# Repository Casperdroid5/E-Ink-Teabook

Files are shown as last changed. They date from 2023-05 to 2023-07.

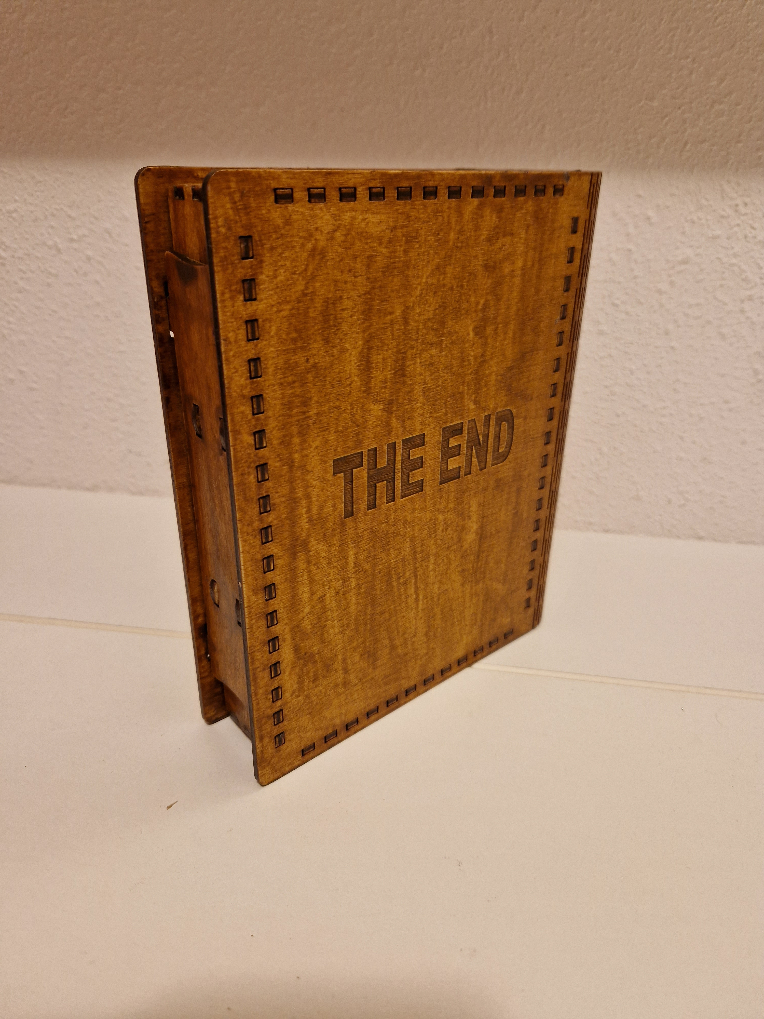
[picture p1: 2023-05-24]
Pictures/back.jpg

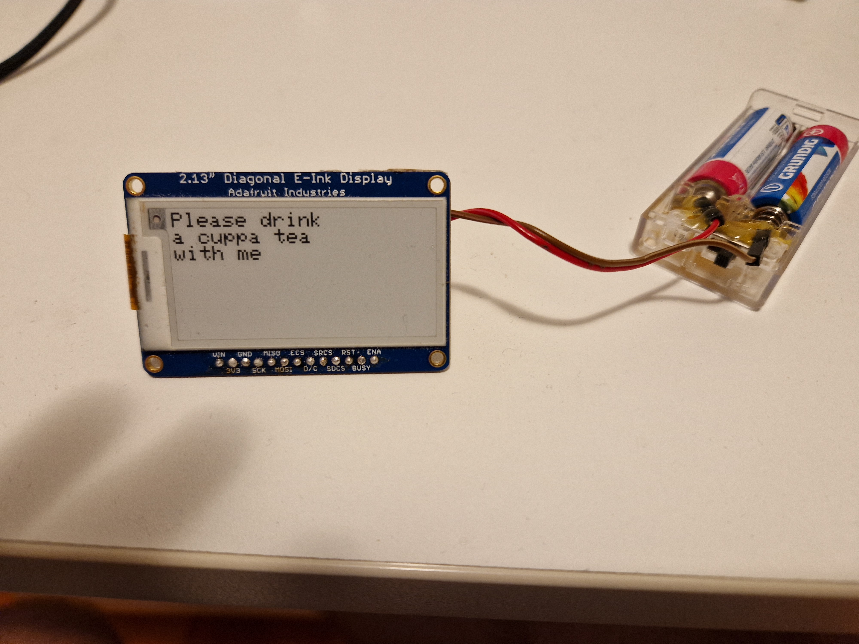
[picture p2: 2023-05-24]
Pictures/seperated display.jpg

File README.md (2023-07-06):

# E-Ink-Teabook

A Teabook with a built-in E-ink display that displays self-help, compliments, and funny texts every other day.

## Hardware Design

The E-Ink-Teabook is designed to be compatible with the following hardware components:

- Arduino Pro Mini 3.3V 8MHz: It is recommended to remove the power LED for energy preservation. Optionally, the voltage regulator can be removed, although it is less secure than leaving it intact.

- Power Source: The system can be powered by 2 AA batteries. However, for optimal performance and system stability, it is highly recommended to use a 4.5V power source such as 3 AA or 3 AAA batteries. Using lower voltage power sources may result in system instability, with the system failing at around 2.7V. The device is very low power with around 31uA current usage when "sleeping". This is thanks to the hardware design of Adafruit's E-ink display (ENA-pin for the ldo is very smart) and some software optimization in the code (low power librarys).

- Display: The Teabook features the Adafruit ThinkInk Mono 2.13-inch monochrome display in black and white. While this display provides excellent performance, there are more cost-effective alternatives available. I strongly advice using the Adafruit E-ink Friend board for a budget-friendly solution. Flexible displays are also an option, but note that the font size may be significantly larger compared to non-flexible displays when using Adafruit's libraries.

By combining the joy of tea with inspirational and humorous messages, the E-Ink-Teabook offers a unique and refreshing experience for daily use.

### Other designs

It is of course possible to use this project for other designs as well. You can think of multiple options:
- Daily motivation "Post-it"
- Daily fun facts painting
- Name tag

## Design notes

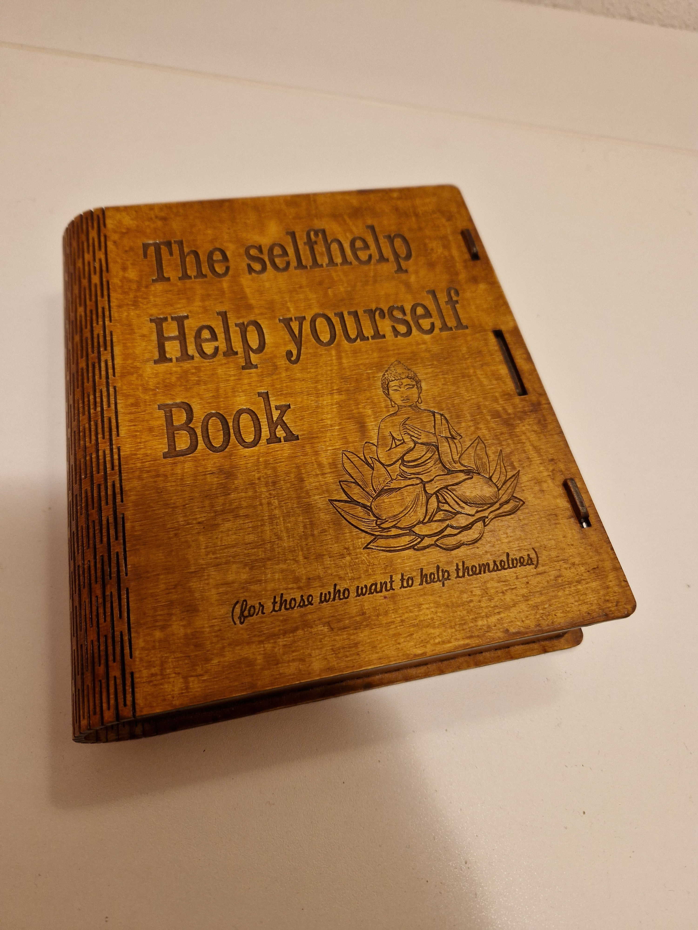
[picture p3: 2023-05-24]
Pictures/bookclosed.jpg

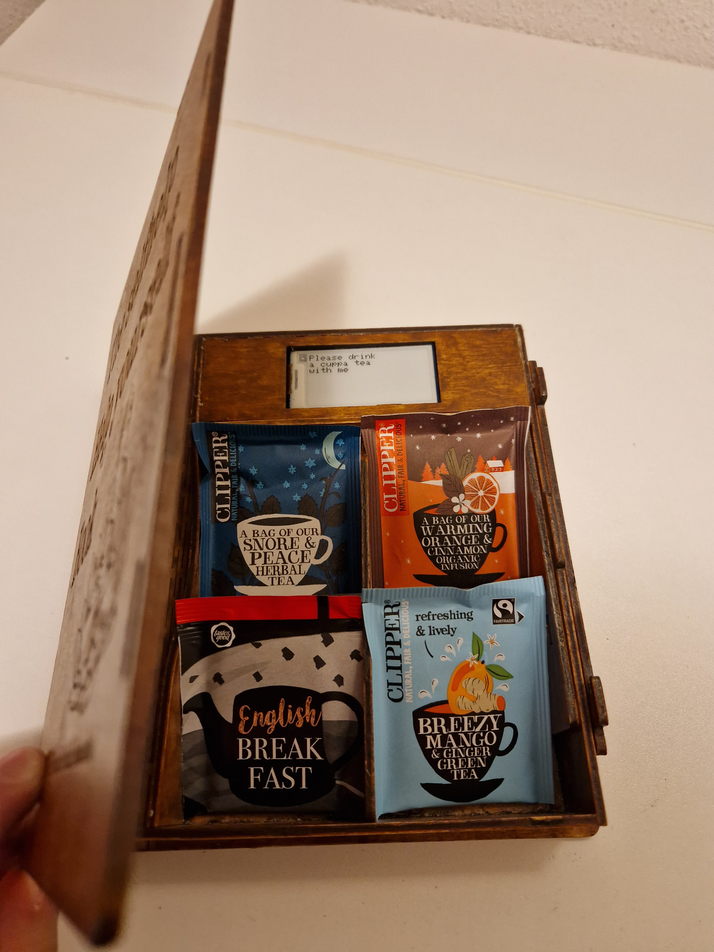
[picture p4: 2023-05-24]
Pictures/lidhalfclosed.jpg

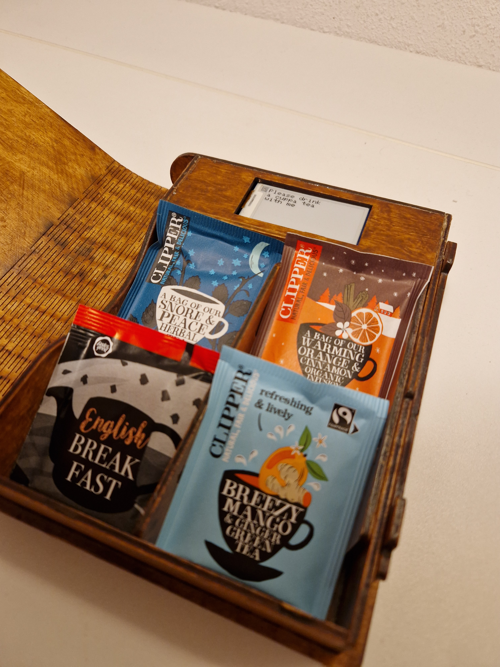
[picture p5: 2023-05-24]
Pictures/openedbook.jpg

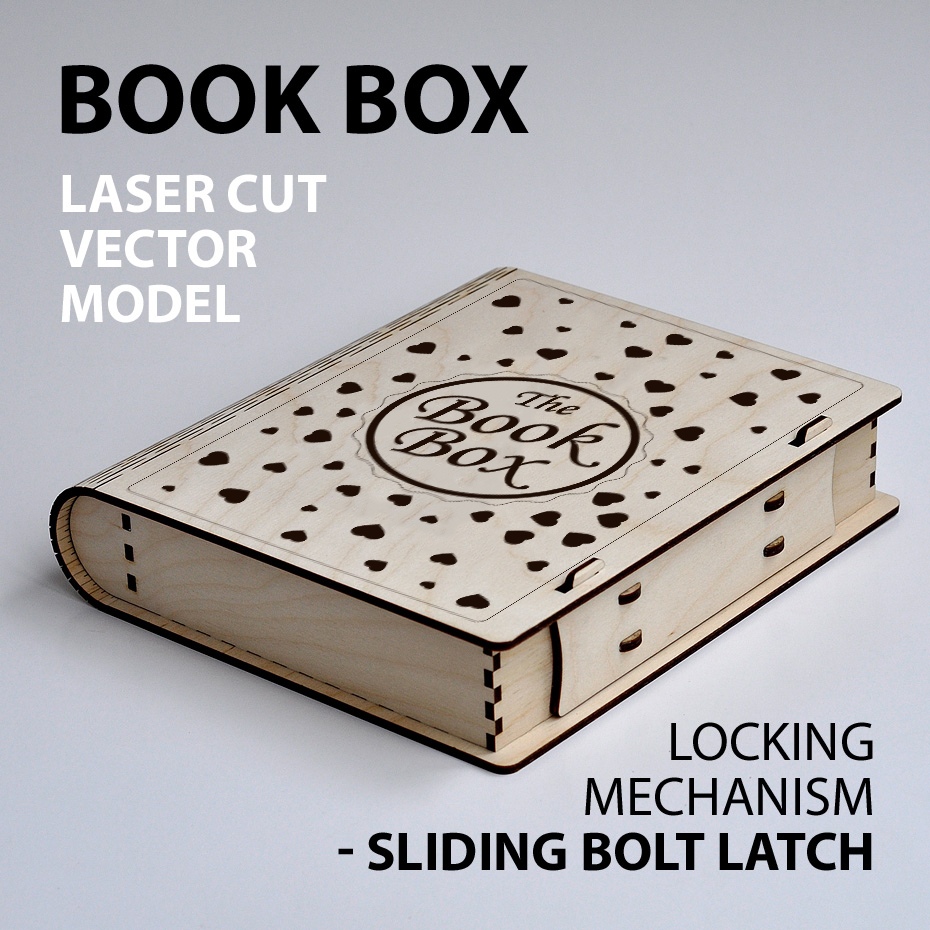
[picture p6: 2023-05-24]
E-ink Teabook/Woodwork/Book template (unedited)/laser cutting vector files free download.jpg

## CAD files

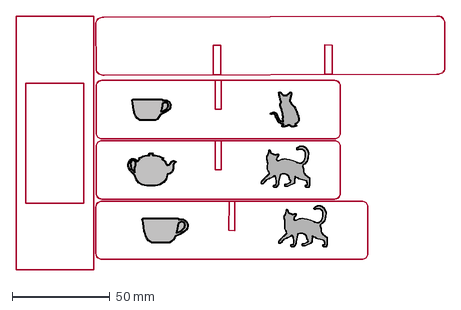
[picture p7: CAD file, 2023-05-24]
E-ink Teabook/Woodwork/2 INTERNALS AND NEW DISPLAY the_book_box CRT.dxf
219.4 x 130.0 mm

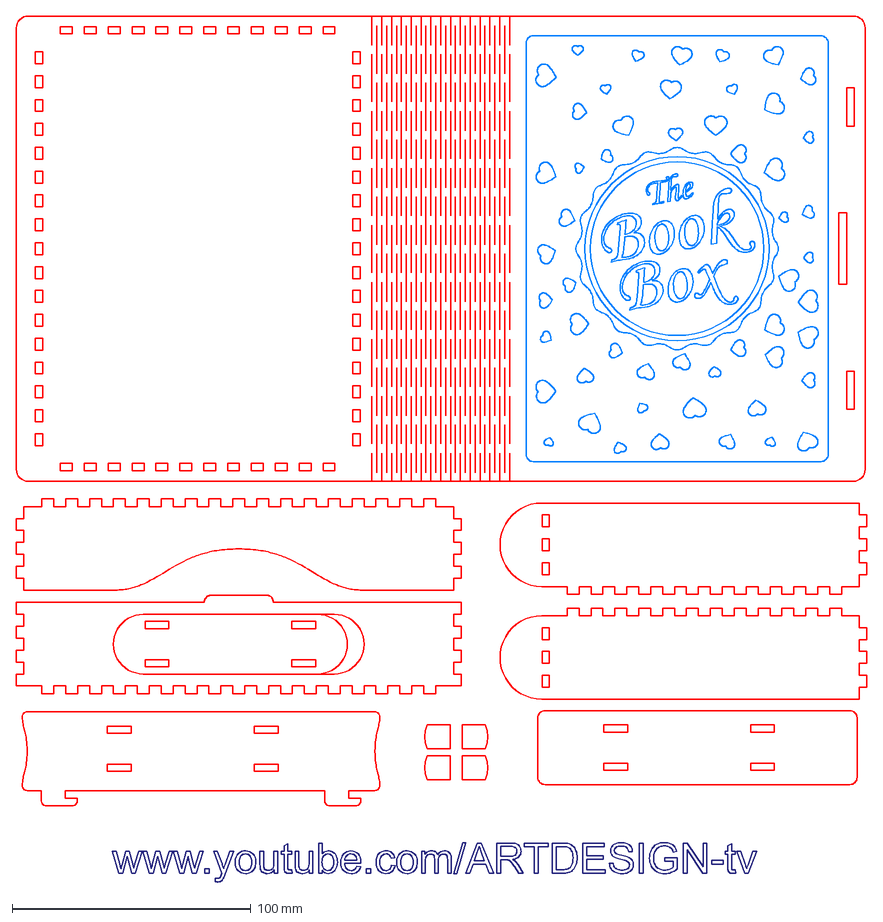
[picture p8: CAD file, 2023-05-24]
E-ink Teabook/Woodwork/Book template (unedited)/the_book_box.dxf
356.3 x 362.9 mm

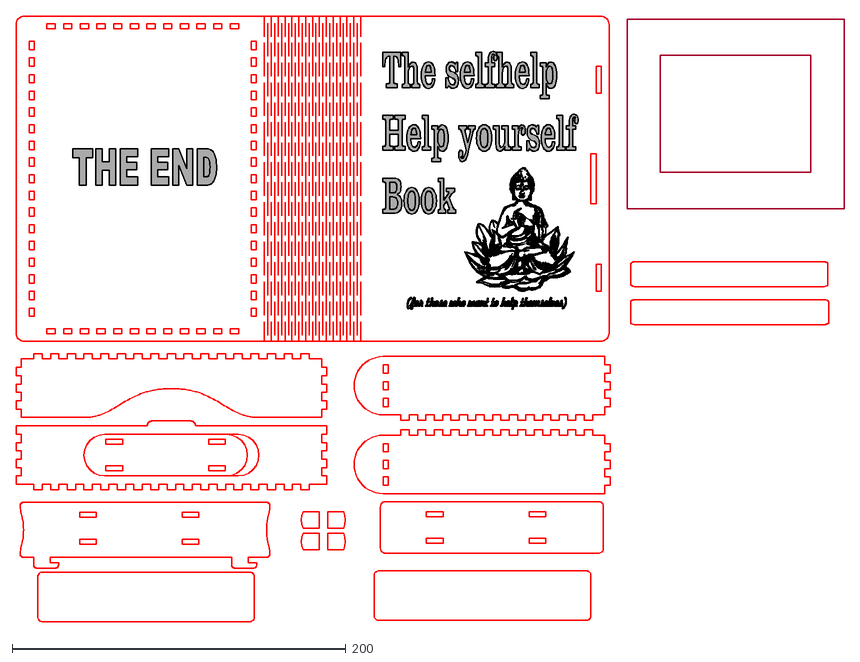
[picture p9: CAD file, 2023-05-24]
E-ink Teabook/Woodwork/the_book_box CRT.dxf
496.5 x 363.1

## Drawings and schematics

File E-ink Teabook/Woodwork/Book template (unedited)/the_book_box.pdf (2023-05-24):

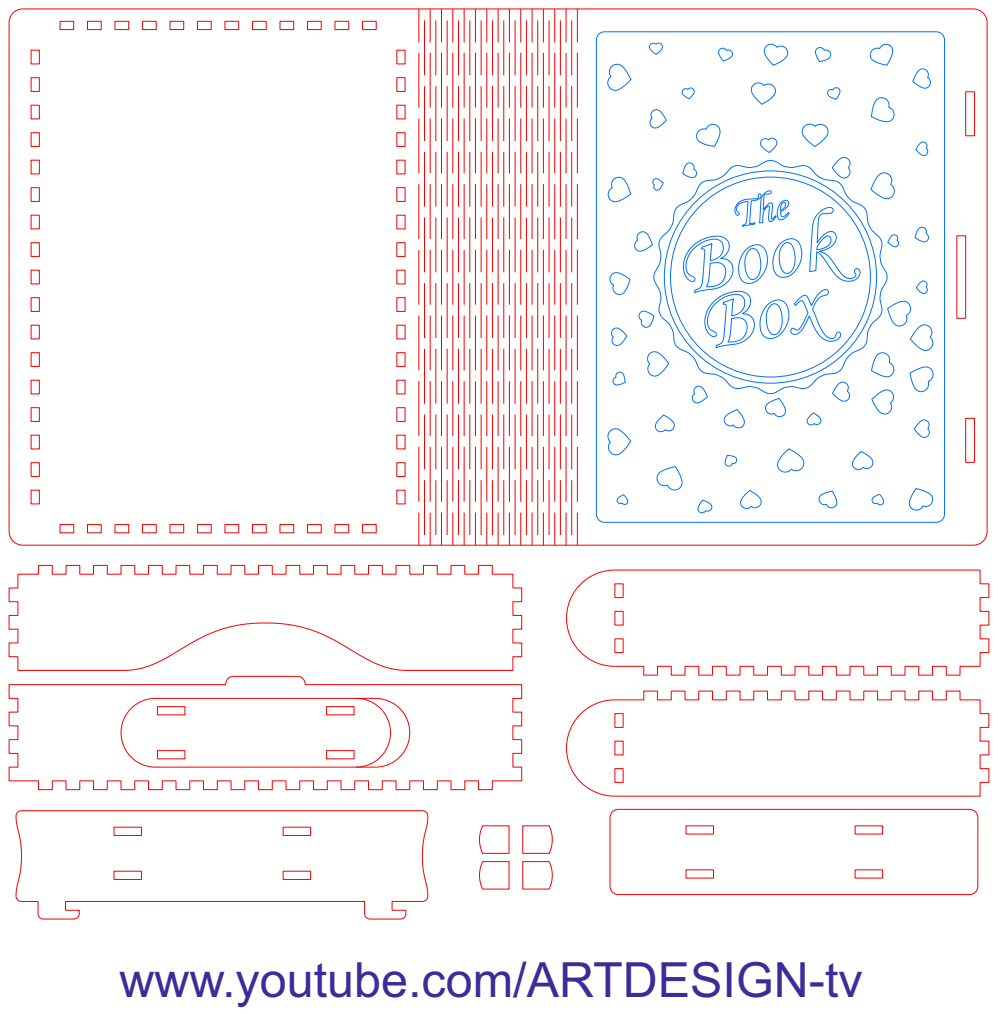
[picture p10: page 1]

www.youtube.com/ARTDESIGN-tv

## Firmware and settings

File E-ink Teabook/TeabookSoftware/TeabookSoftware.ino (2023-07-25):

#include "Adafruit_ThinkInk.h"
#include "Texts.h"
#include <LowPower.h>

// Pin definitions
#define EPD_CS 10
#define EPD_DC 9
#define SRAM_CS 8
#define EPD_RESET 5
#define EPD_BUSY 3

// Color settings
#define BLACK EPD_BLACK
#define RED EPD_RED


//----Display selector----//

//Flexible display
//Adafruit_IL0373 display(212, 104, EPD_DC, EPD_RESET, EPD_CS, SRAM_CS, EPD_BUSY);
//#define FLEXIBLE_213 // uncomment for flexible display size setting (required)

// 2.13" Monochrome displays with 250x122 pixels and SSD1680 chipset
ThinkInk_213_Mono_BN display(EPD_DC, EPD_RESET, EPD_CS, SRAM_CS, EPD_BUSY);

const int TimeToWaitInSeconds = (86400 / 8);  // amount of seconds to wait devided by the 8 seconds of powerdown. 86400 seconds = a day
int currentIndex = 0;                     // Variable to keep track of the current text index

const int ENAPin = 4;  // Ultra low power EPD pin

char buffer[MAX_TEXT_LENGTH + 1];  // Buffer to store the retrieved text

int counter = 0;

void setup() {

  display.begin();
#if defined(FLEXIBLE_213) || defined(FLEXIBLE_290)  // for flexible displays
  display.setBlackBuffer(1, false);
  display.setColorBuffer(1, false);
#endif
  drawimageEPD("Selfhelp Teabook\nby:\nCasper\n\nMade with love for:\nAlys" , BLACK);
  delay(3000);
  drawimageEPD("\nAfter all this time\nyou will find Alys,\nthat you were \nalready perfect\n\n  from the start" , BLACK);
  pinMode(EPD_RESET, OUTPUT);
  pinMode(ENAPin, OUTPUT);
}

void loop() {
  if (counter >= TimeToWaitInSeconds) {
    delay(10);
    digitalWrite(ENAPin, HIGH);  // Enable screen
    delay(50);
    drawimageEPD(getNextText(), BLACK);
    delay(10);
    digitalWrite(ENAPin, LOW);  // Disable screen
    counter = 0;
  }
  LowPower.powerDown(SLEEP_8S, ADC_OFF, BOD_OFF);  // go into sleep mode for extreme power saving
  counter = counter + 1;
}

void drawimageEPD(const char* text, uint16_t color) {
  display.begin();
  display.clearBuffer();
  display.setCursor(0, 0);
  display.setTextSize(2);
  display.setTextColor(color);
  display.setTextWrap(true);
  display.print(text);
  display.display();
}

const char* getNextText() {
  strncpy_P(buffer, (char*)pgm_read_word(&(Texts[currentIndex])), MAX_TEXT_LENGTH);
  buffer[MAX_TEXT_LENGTH] = '\0';
  currentIndex = (currentIndex + 1) % TEXT_COUNT;
  return buffer;
}

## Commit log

2023-05-24 Added project to Github
    [2 INTERNALS AND NEW DISPLAY the_book_box CRT.dxf, the_book_box CRT.dxf, the_book_box.dxf]
2023-05-26 possible fix for white screen
    [TeabookSoftware.ino]
2023-05-26 back to the start.
    Problem lies within the powerdown.powerdown function in combination with adafruit eink display
    [TeabookSoftware.ino]
2023-05-26 trying avr low power librarys
2023-05-27 possibly found the problem: ENAPIN low position
    [TeabookSoftware.ino]
2023-05-27 most likely fixed the issue
    [TeabookSoftware.ino]
2023-06-21 possibly fixed white screen again
    - By adding extra delays and display begin
    - Disabled serial
    [TeabookSoftware.ino]
2023-06-21 fixed white screen most likely
    [TeabookSoftware.ino]
